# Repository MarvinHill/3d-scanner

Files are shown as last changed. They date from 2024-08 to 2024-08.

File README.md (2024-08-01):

# 3d-scanner
This project contains software and 3d files for a 3d Scanner developed for the Virtual Reality Course at Hochschule Heilbronn in SoSE 2024.
## Showcase

blueprint

https://github.com/user-attachments/assets/66f47e95-8ec8-498e-958c-c9a36b86d276

## Features
- Manual control of the scanner movement on two axis
- Motor leveling of the axis that holds the camera with end-switches
- Automated photo mode where the scanner takes a specified amount of photos from multiple distributed angles, so that the images cover the object from all Sites
## Structure
- configuration: contains ansible playbooks to configure the rpi and install the scanner firmware, and caddy webserver.
- firmware-rpi: contains firmware to controll the scanner
- frontent-scanner: contains the frontend for the webservice to controll the scanner with a graphical ui
- 3d: contains 3d files to build the scanner
## 3D Modells
stl files can be found in the 3d folder, look at the blueprint in the readme to understand where which part fits
## Used Hardware
- Raspberry Pi zero 2w
- m3 screws & m3 threat inserts
- eleego cabels
- ELEGOO stepper motor x3 and driver board ULN2003 x3
- 3d Printer & Filament
- endswitch
### Pins
- motor table axis: pins           index [3 5 7 11]
- motor one camera: pins           index [23 29 31 33]
- motor two camera: pins           index [8 10 12 16]
- endswitch one: pins              index [in:36, out:35]
- endswitch two: pins              index [in:38, out:37]

### Driver
The gobot driver for stepper motors was used to controll the scanner 2 axis.

## Software
### Linux RPI Configuration

install ansible and docker on host system
install pi-blaster (for gobot if older rpi is used, not needed for newer) 

### Gobot setup
oder version of rpi
[issue link](https://github.com/hybridgroup/gobot/issues/691)
### Build go
[How To Build](https://www.digitalocean.com/community/tutorials/building-go-applications-for-different-operating-systems-and-architectures)

linux: 
command: GOOS=linux GOARCH=arm GOARM=6 go build -o ./build/scanner

windows:
(set GOOS=linux) & (set GOARCH=arm) & (set GOARM=6) & go build -o ./build/scanner

- run docker compose to build the artifacts
- then run the ansible playbook `ansible-playbook -i production site.yml`

### Copy to rpi
scp scanner marvin@192.168.188.59:/tmp

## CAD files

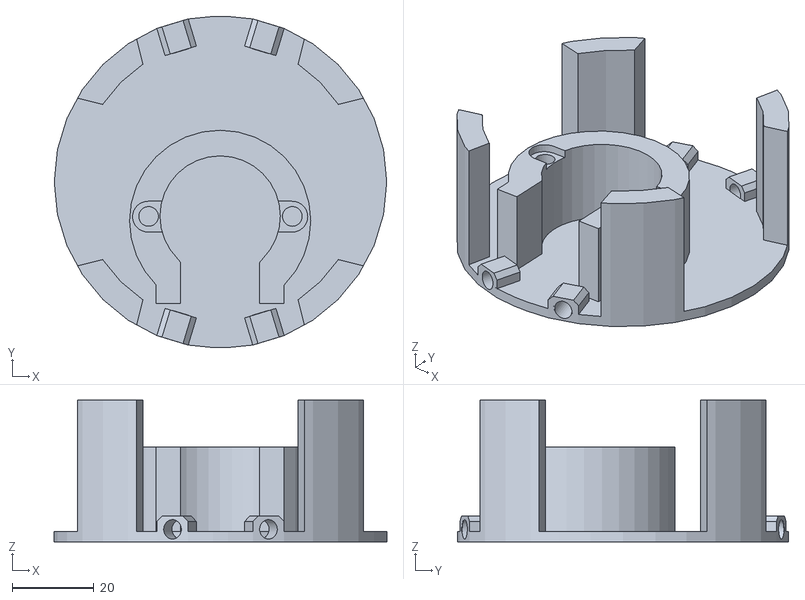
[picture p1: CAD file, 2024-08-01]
3d/baseplate.stl
81.1 x 80.8 x 34.6

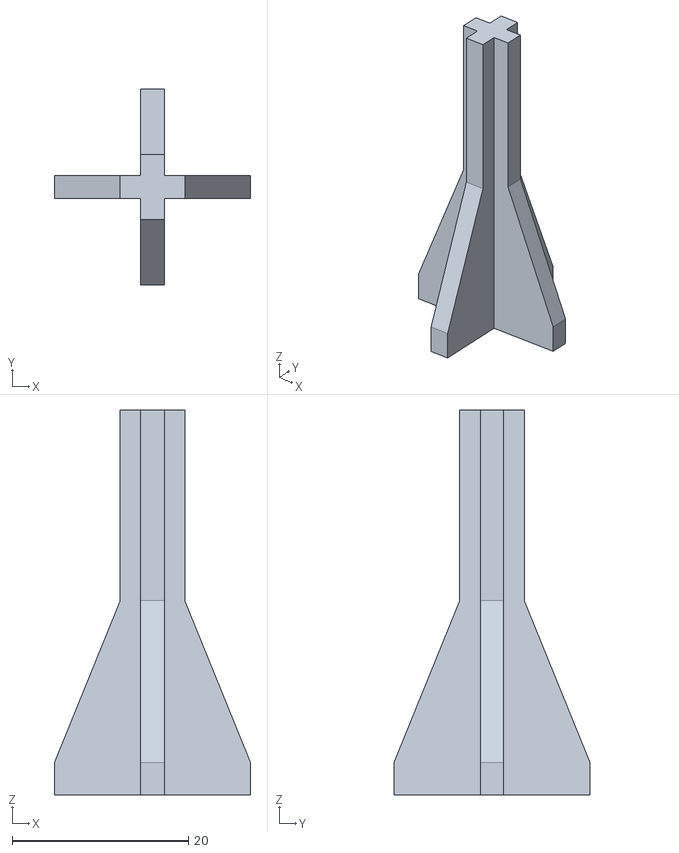
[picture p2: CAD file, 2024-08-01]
3d/heighttool.stl
22.3 x 22.3 x 43.7

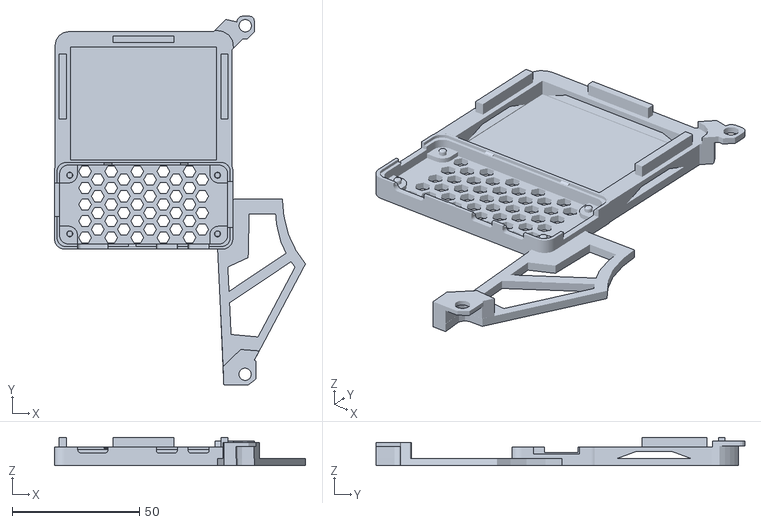
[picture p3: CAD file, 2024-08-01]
3d/case1.stl
98.5 x 144.9 x 11.1

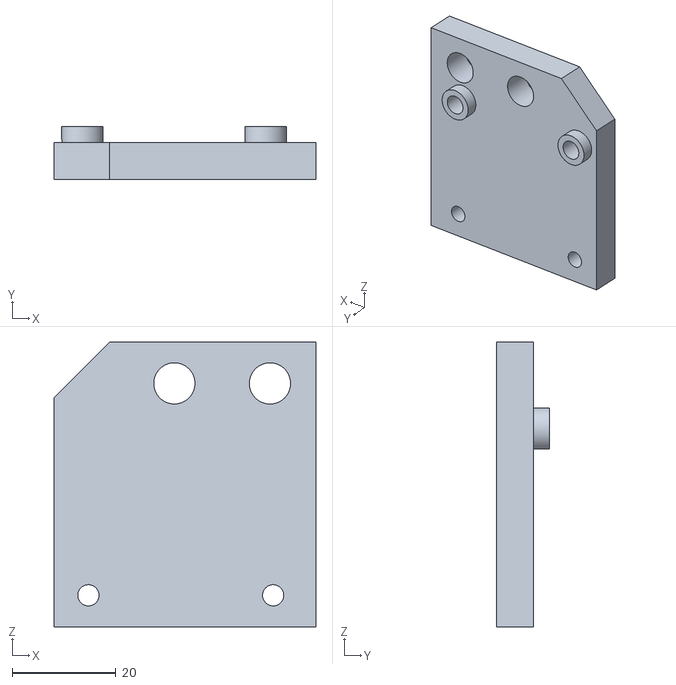
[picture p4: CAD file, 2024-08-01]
3d/plate.stl
50.5 x 10.2 x 55.0

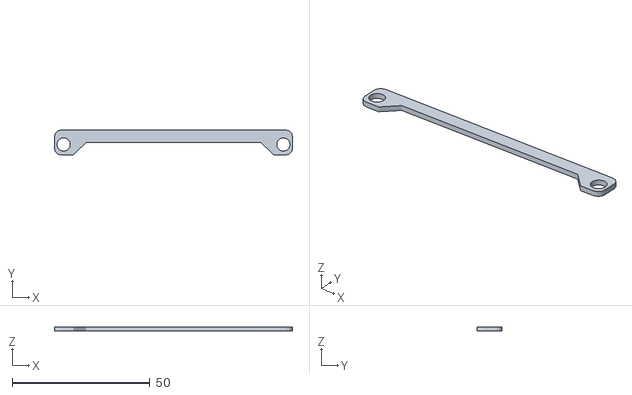
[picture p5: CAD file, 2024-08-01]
3d/motordriver2.stl
86.5 x 9.09 x 1.59

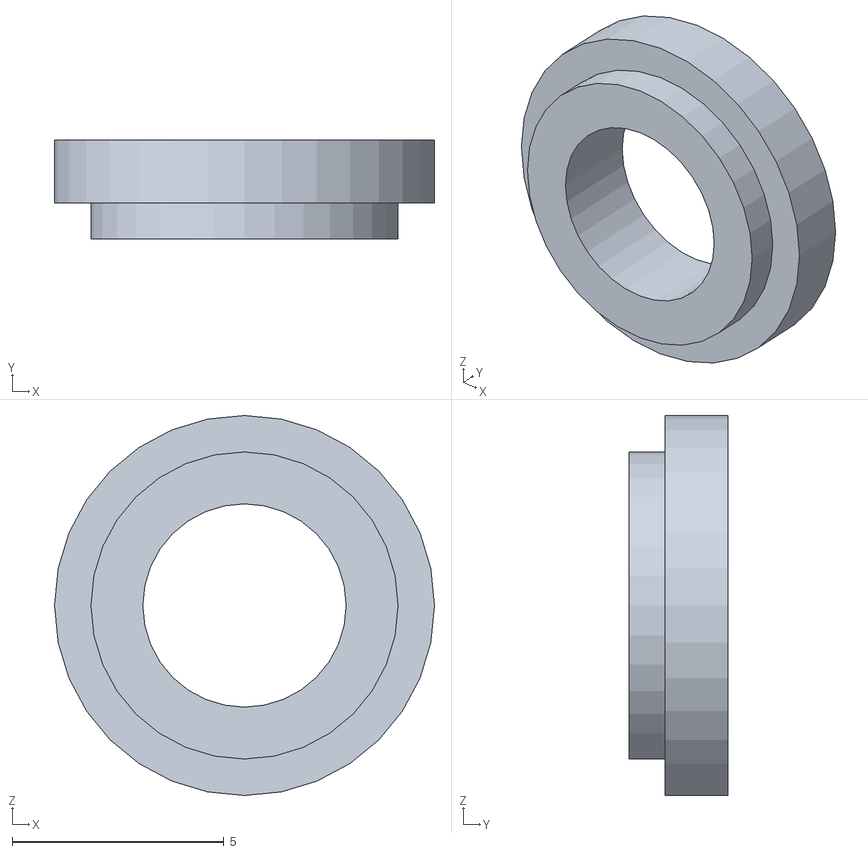
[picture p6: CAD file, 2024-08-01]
3d/gear1adapter.stl
8.98 x 2.35 x 8.98

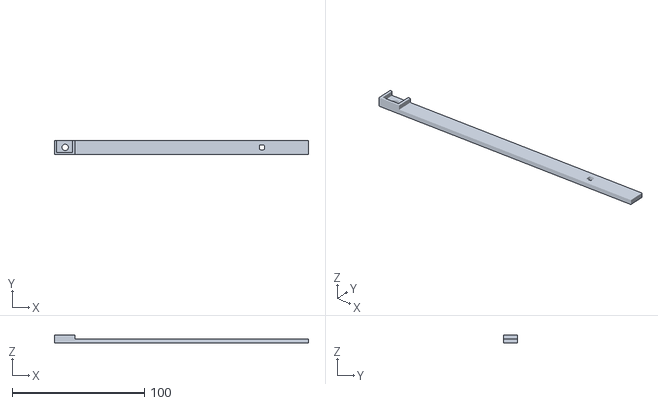
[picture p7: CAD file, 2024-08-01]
3d/holder2.stl
191.8 x 10.8 x 5.97

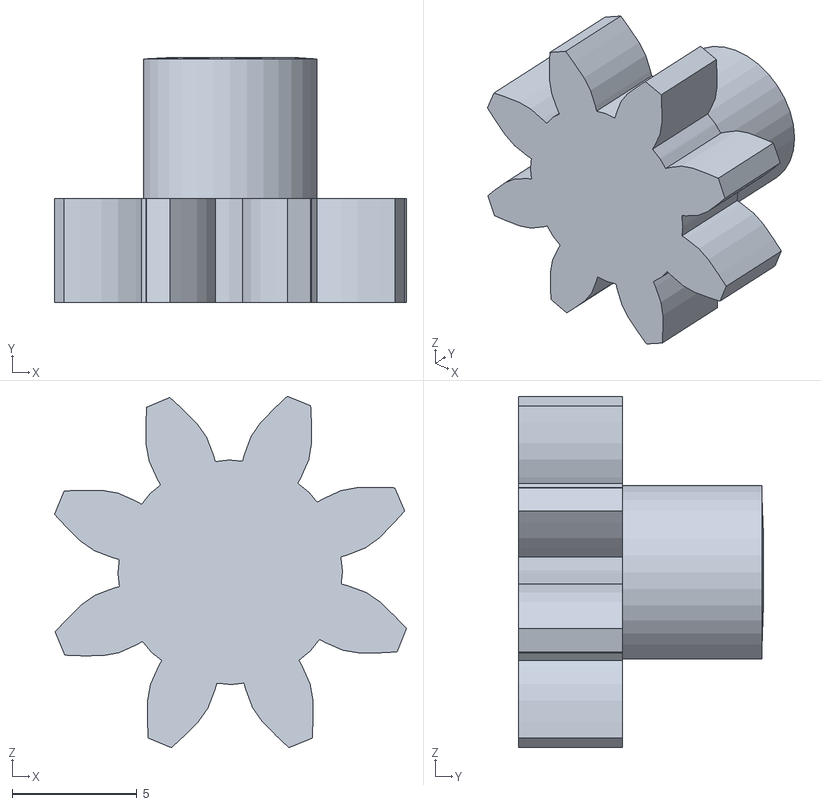
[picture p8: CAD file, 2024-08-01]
3d/gear2.stl
14.1 x 9.82 x 14.1

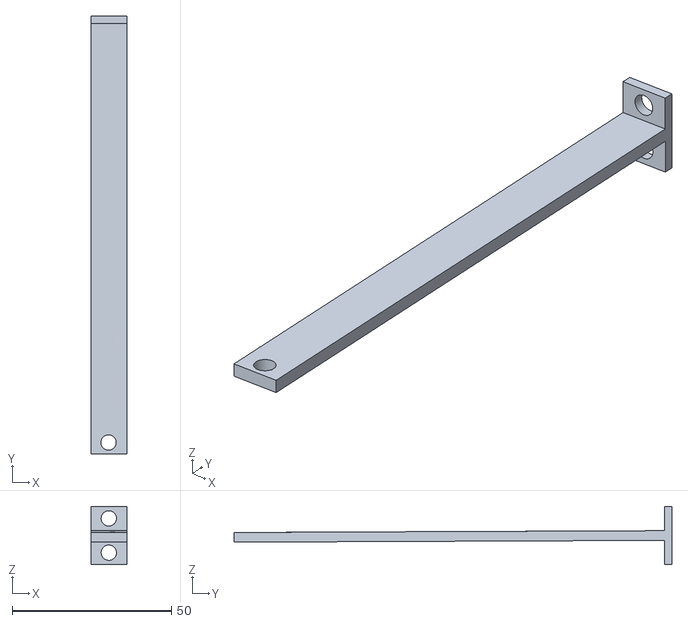
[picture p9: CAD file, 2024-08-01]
3d/holder1.stl
11.4 x 137.4 x 18.3

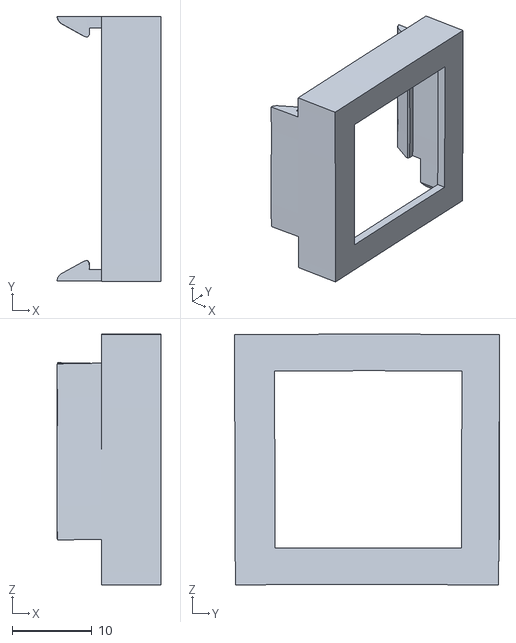
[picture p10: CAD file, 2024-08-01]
3d/camholder2.stl
13.1 x 33.3 x 31.5

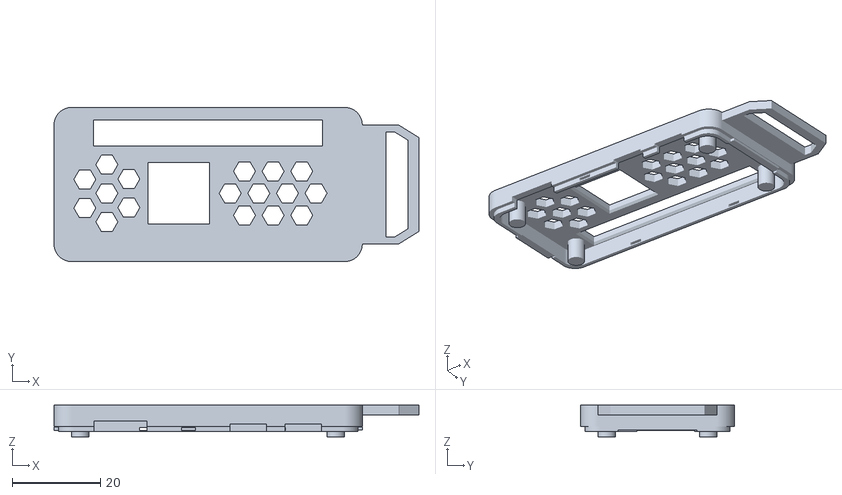
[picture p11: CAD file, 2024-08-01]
3d/case2.stl
82.9 x 35.0 x 7.20

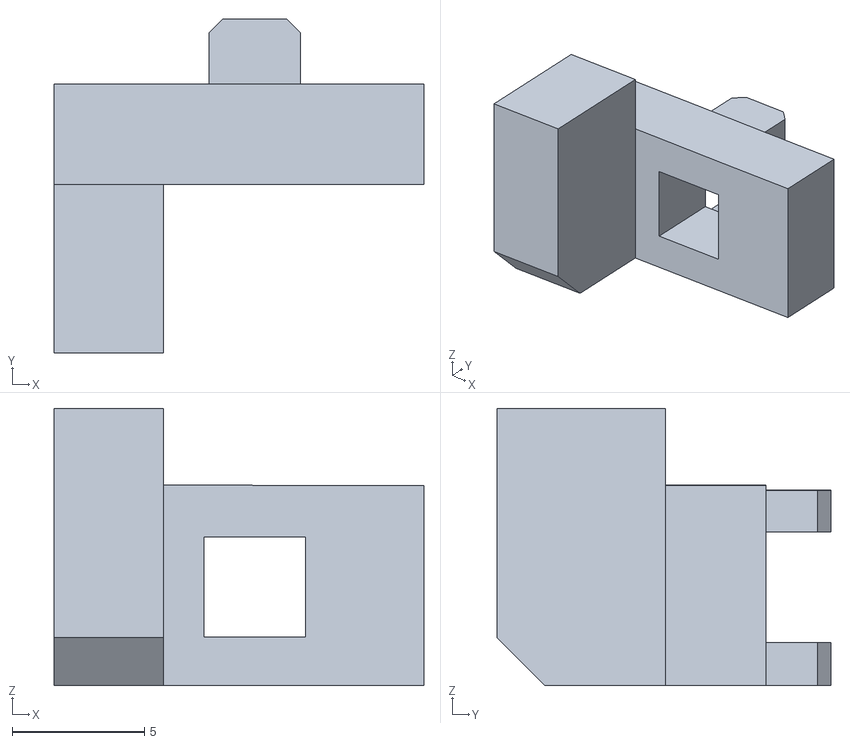
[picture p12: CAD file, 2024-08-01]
3d/endswitch2.stl
14.0 x 12.6 x 10.5

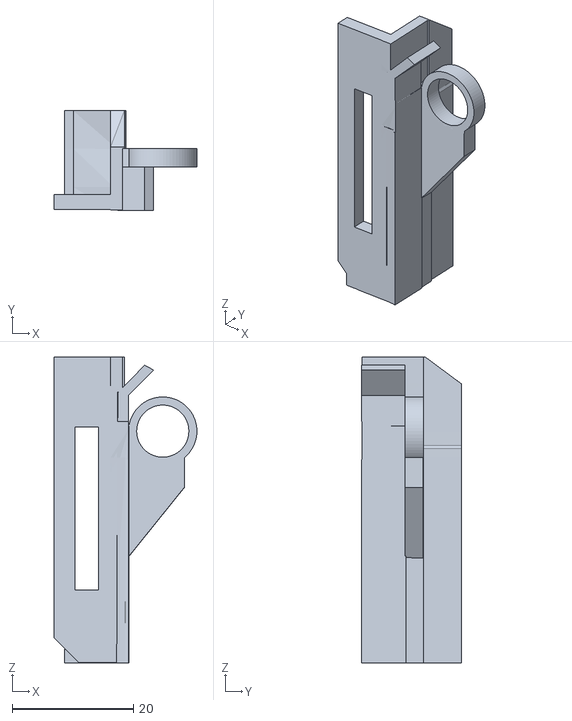
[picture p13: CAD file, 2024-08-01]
3d/endswitch1.stl
23.6 x 16.4 x 50.5

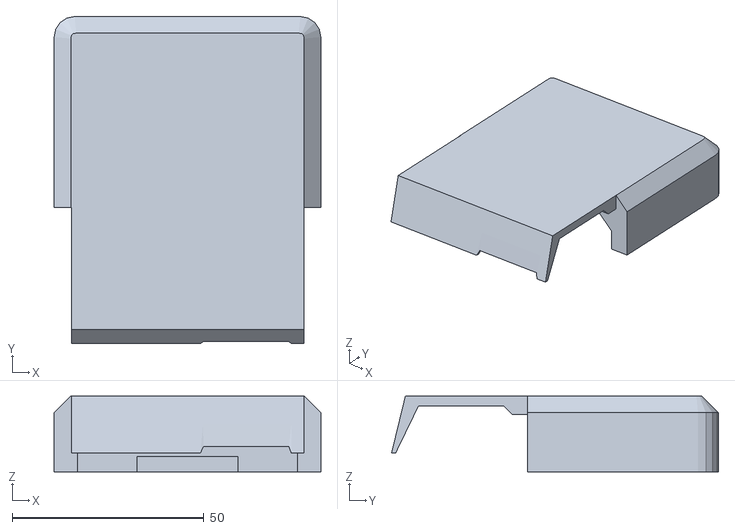
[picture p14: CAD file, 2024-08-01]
3d/case3.stl
69.5 x 85.2 x 19.8

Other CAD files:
3d/camholder1.stl
3d/gear1.stl
3d/table.stl
3d/stabplate.stl
3d/adjustablearm.stl
3d/motordriver1.stl

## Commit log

2024-07-06 feat: added motor sleep to scanner leveling
2024-07-14 feat: raised camera axis to 40 deg
2024-07-15 fix: maybe fix of current postion when wlan disconnects
2024-08-01 feat: added 3d files
    [adjustablearm.stl, baseplate.stl, camholder1.stl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]
